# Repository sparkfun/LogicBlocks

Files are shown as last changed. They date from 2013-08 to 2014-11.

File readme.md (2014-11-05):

LogicBlocks Kit
============================

[LogicBlocks Kit  
*LogicBlocks Kit (KIT-11006)*](https://www.sparkfun.com/products/11006)

LogicBlocks allow you to play with logic gates by literally plugging one into another and watching the progression of an input to an output! Each LogicBlock represents a different logic function: the NOT block is a simple inverter, where the output is the opposite of the input. The AND block will only output a 1 if both of the inputs are 1. The OR block will output a 1 if either of the inputs are 1. There are also input blocks and splitter blocks.

Repository Contents
-------------------
* **/Hardware** - All Eagle design files (.brd, .sch)

License Information
-------------------
The hardware is released under [Creative Commons ShareAlike 4.0 International](https://creativecommons.org/licenses/by-sa/4.0/).

Distributed as-is; no warranty is given.

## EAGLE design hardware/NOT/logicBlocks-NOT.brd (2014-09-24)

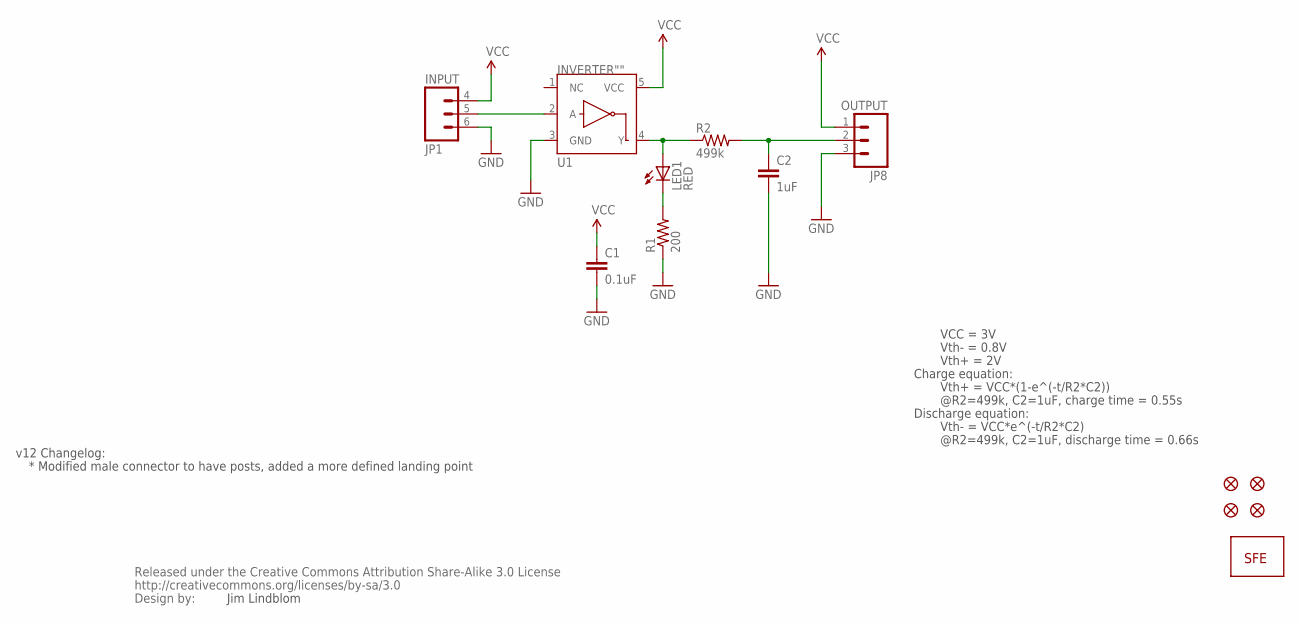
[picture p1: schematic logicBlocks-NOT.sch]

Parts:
C1: 0.1uF; 0402-CAP
C2: 1uF; 0402-CAP
FID1, FID2, FID3, FID4: FIDUCIAL1X2; FIDUCIAL-1X2
JP1: INPUT; 1X03-SMD-FEMALE
JP4: LOGO-SFESK; SFE-LOGO-FLAME
JP8: OUTPUT; 1X03_SMD_RA_MALE_POST
LED1: RED; LED-1206
R1: 200; 0402-RES
R2: 499k; 0402-RES
U1: INVERTER""; SC70
U$2: CREATIVE_COMMONS

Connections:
GND: C1.2, C2.2, JP1.6 (3), JP8.3, R1.1, U1.3 (GND)
unnamed: LED1.C, R1.2
unnamed: JP1.5 (2), U1.2 (A)
unnamed: LED1.A, R2.1, U1.4 (Y)
unnamed: C2.1, JP8.2, R2.2
VCC: C1.1, JP1.4 (1), JP8.1, U1.5 (VCC)

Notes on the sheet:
Jim Lindblom
Charge equation:
Vth+ = VCC*(1-e^(-t/R2*C2))
Vth+ = 2V
Vth- = 0.8V
@R2=499k, C2=1uF, charge time = 0.55s
Discharge equation:
Vth- = VCC*e^(-t/R2*C2)
@R2=499k, C2=1uF, discharge time = 0.66s
v12 Changelog:
* Modified male connector to have posts, added a more defined landing point
VCC = 3V

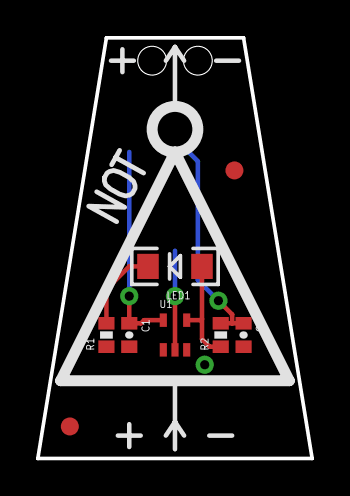
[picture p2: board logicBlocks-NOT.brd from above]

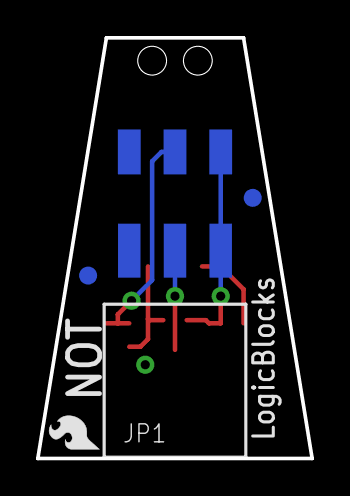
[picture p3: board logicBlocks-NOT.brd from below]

Board: 2 copper layers, 15.2 x 23.4 mm, 14 parts (5 on the bottom side), 6 nets.

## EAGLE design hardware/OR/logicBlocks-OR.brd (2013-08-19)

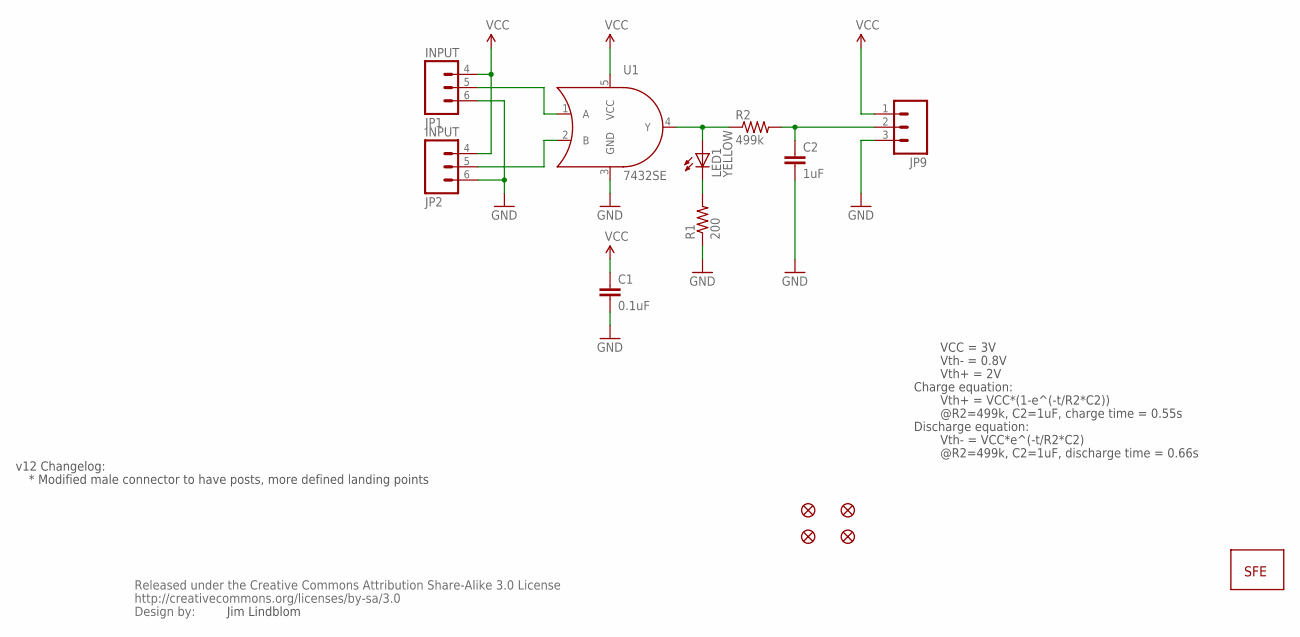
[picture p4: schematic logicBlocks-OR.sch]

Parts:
C1: 0.1uF; 0402-CAP
C2: 1uF; 0402-CAP
JP1, JP2: INPUT; 1X03-SMD-FEMALE
JP4: LOGO-SFESK; SFE-LOGO-FLAME
JP5, JP6, JP7, JP8: FIDUCIALUFIDUCIAL; MICRO-FIDUCIAL
JP9: M03SMD_RA_MALE_POST; 1X03_SMD_RA_MALE_POST
LED1: YELLOW; LED-1206
R1: 200; 0402-RES
R2: 499k; 0402-RES
U1: 7432SE; SOT353
U$2: CREATIVE_COMMONS

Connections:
GND: C1.2, C2.2, JP1.6 (3), JP2.6 (3), JP9.3, R1.1, U1.3 (GND)
unnamed: LED1.C, R1.2
unnamed: JP1.5 (2), U1.1 (A)
unnamed: JP2.5 (2), U1.2 (B)
unnamed: LED1.A, R2.1, U1.4 (Y)
unnamed: C2.1, JP9.2, R2.2
VCC: C1.1, JP1.4 (1), JP2.4 (1), JP9.1, U1.5 (VCC)

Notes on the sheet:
Jim Lindblom
Charge equation:
Vth+ = VCC*(1-e^(-t/R2*C2))
Vth+ = 2V
Vth- = 0.8V
@R2=499k, C2=1uF, charge time = 0.55s
Discharge equation:
Vth- = VCC*e^(-t/R2*C2)
@R2=499k, C2=1uF, discharge time = 0.66s
v12 Changelog:
VCC = 3V
* Modified male connector to have posts, more defined landing points

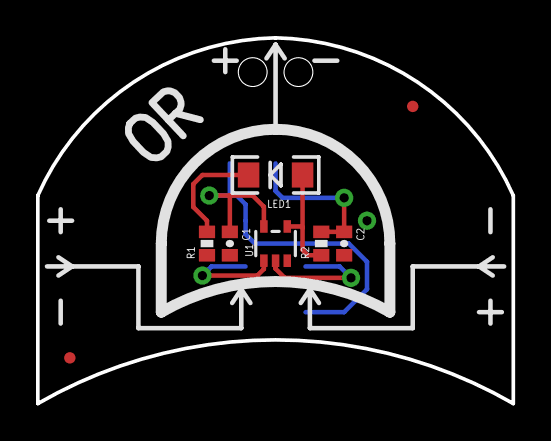
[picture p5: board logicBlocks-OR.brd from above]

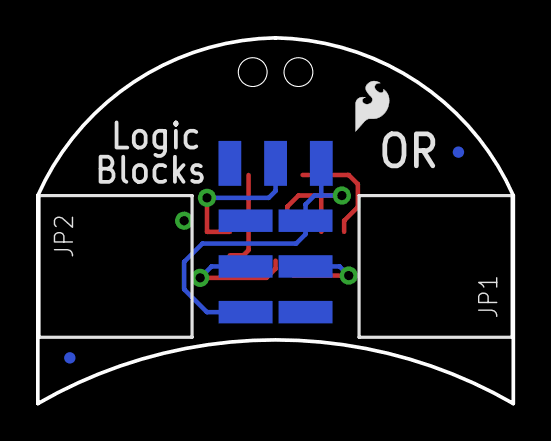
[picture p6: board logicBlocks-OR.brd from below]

Board: 2 copper layers, 26.4 x 20.3 mm, 15 parts (6 on the bottom side), 7 nets.

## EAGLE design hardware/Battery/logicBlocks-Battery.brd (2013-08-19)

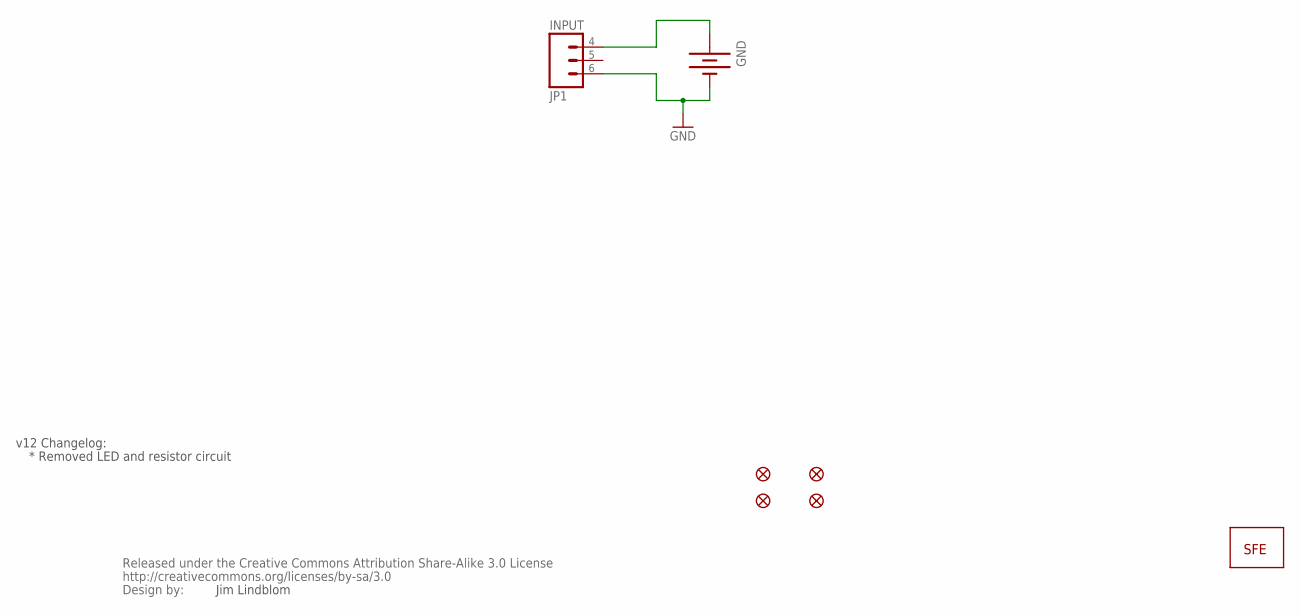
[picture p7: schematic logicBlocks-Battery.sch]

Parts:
GND: BATTERY20MM_4LEGS; BATTCON_20MM_4LEGS
JP1: INPUT; 1X03-SMD-FEMALE
JP3: LOGO-SFESK; SFE-LOGO-FLAME
JP4, JP5, JP6, JP7: FIDUCIALUFIDUCIAL; MICRO-FIDUCIAL
U$2: CREATIVE_COMMONS

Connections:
GND: GND.2 (-), JP1.6 (3)
VCC: GND.1 (+), JP1.4 (1)

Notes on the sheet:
Jim Lindblom
v12 Changelog:
* Removed LED and resistor circuit

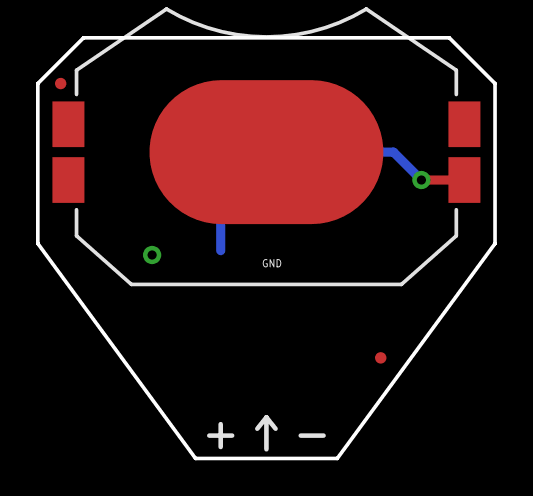
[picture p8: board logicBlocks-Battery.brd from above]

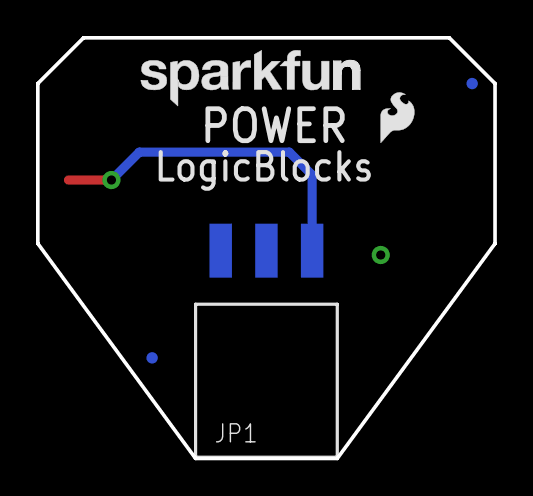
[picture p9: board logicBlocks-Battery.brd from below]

Board: 2 copper layers, 25.4 x 23.4 mm, 9 parts (5 on the bottom side), 2 nets.

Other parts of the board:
JP2: LOGO-SFENW2; SFE-NEW-WEB

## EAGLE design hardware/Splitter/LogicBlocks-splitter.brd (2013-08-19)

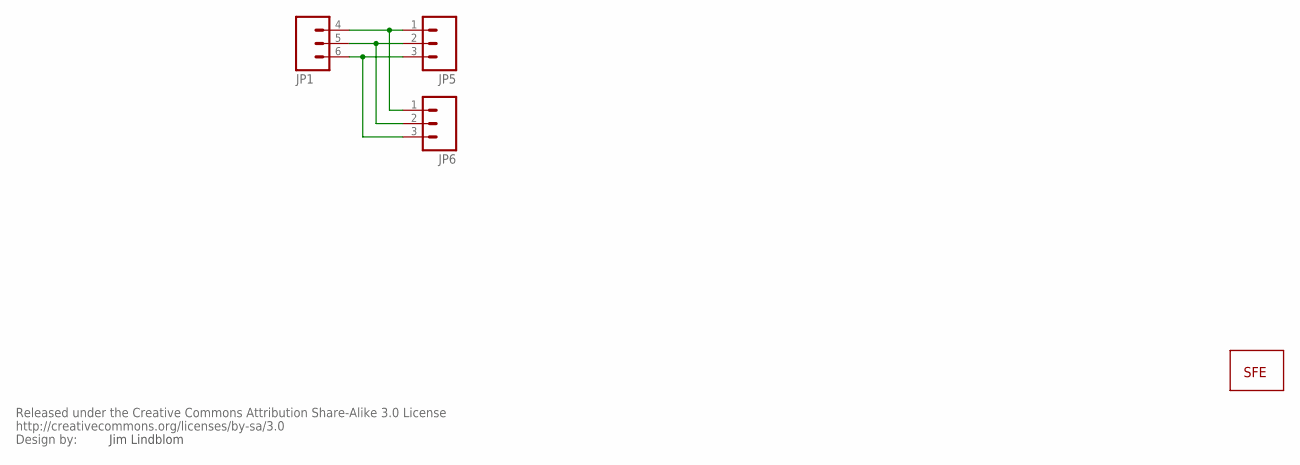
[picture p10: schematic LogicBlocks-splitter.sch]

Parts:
JP1: M03SMD-RA-FEMALE; 1X03-SMD-FEMALE
JP4: LOGO-SFESK; SFE-LOGO-FLAME
JP5, JP6: M03SMD_RA_MALE_POST; 1X03_SMD_RA_MALE_POST
U$1: CREATIVE_COMMONS

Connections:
GND: JP1.6 (3), JP5.3, JP6.3
S: JP1.5 (2), JP5.2, JP6.2
VCC: JP1.4 (1), JP5.1, JP6.1

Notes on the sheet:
Jim Lindblom

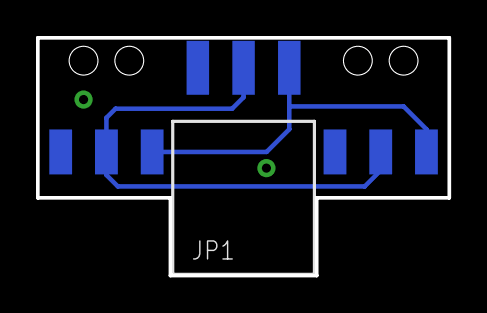
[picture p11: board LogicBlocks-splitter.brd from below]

Board: 2 copper layers, 22.9 x 13.2 mm, 5 parts (3 on the bottom side), 3 nets.

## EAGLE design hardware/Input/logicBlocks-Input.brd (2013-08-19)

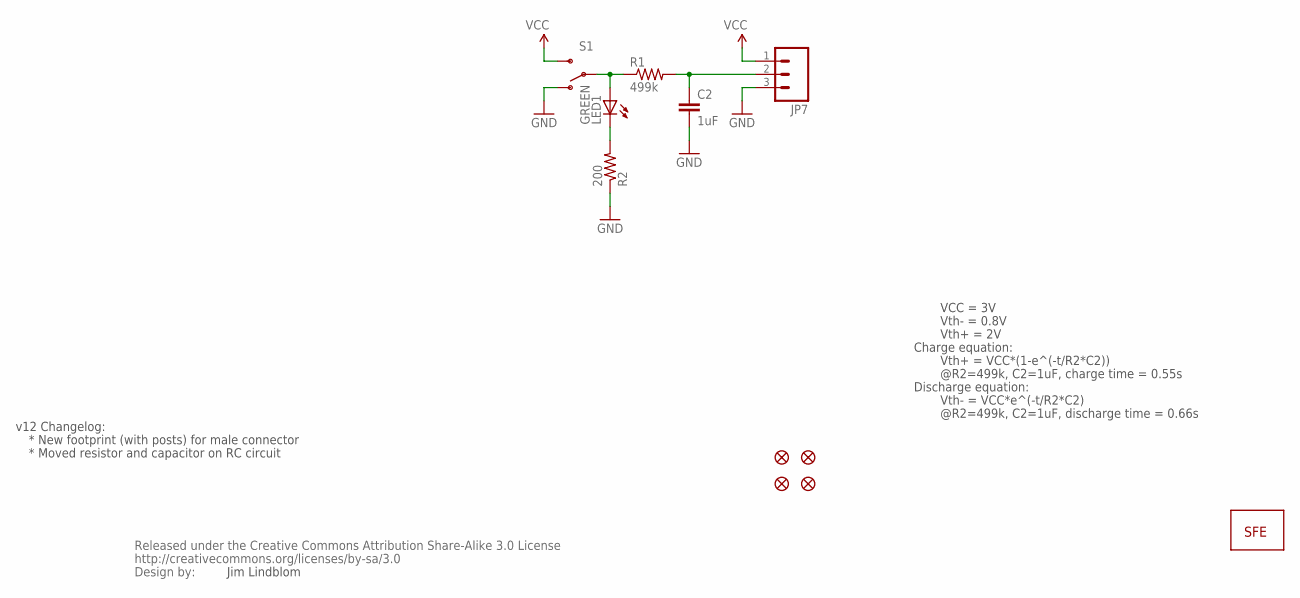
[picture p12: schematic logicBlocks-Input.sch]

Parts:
C2: 1uF; 0402-CAP
JP2: LOGO-SFESK; SFE-LOGO-FLAME
JP3, JP4, JP5, JP6: FIDUCIALUFIDUCIAL; MICRO-FIDUCIAL
JP7: M03SMD_RA_MALE_POST; 1X03_SMD_RA_MALE_POST
LED1: GREEN; LED-1206
R1: 499k; 0402-RES
R2: 200; 0402-RES
S1: SWITCH-SPSTSMD; AYZ0202
U$2: CREATIVE_COMMONS

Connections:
GND: C2.2, JP7.3, R2.1, S1.1 (O)
unnamed: C2.1, JP7.2, R1.2
unnamed: LED1.A, R1.1, S1.2
unnamed: LED1.C, R2.2
VCC: JP7.1, S1.3 (S)

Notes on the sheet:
Jim Lindblom
Charge equation:
Vth+ = VCC*(1-e^(-t/R2*C2))
Vth+ = 2V
Vth- = 0.8V
@R2=499k, C2=1uF, charge time = 0.55s
Discharge equation:
Vth- = VCC*e^(-t/R2*C2)
@R2=499k, C2=1uF, discharge time = 0.66s
v12 Changelog:
VCC = 3V
* New footprint (with posts) for male connector
* Moved resistor and capacitor on RC circuit



Board: 2 copper layers, 10.2 x 16.5 mm, 12 parts (5 on the bottom side), 5 nets.

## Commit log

2013-08-19 v11 (currently live) of all boards
    Also initial commit of readme.md
    [LogicBlocks-splitter.brd, LogicBlocks-splitter.sch, logicBlocks-AND.brd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]
2013-08-19 v12 of all boards -- Male headers w/ posts
    [LogicBlocks-splitter.brd, LogicBlocks-splitter.sch, logicBlocks-AND.brd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]
2014-09-24 changed to regular fiducials
    [logicBlocks-NOT.brd, logicBlocks-NOT.sch]

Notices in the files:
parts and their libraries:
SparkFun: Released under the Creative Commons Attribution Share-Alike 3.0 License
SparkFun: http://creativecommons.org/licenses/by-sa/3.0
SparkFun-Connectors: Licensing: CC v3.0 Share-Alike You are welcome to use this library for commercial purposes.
